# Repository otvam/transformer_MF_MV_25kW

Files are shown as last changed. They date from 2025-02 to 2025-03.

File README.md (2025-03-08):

# 25kW/50kHz MF/MV Transformer / CAD files






This repository contains the **CAD files** for a 25kW/50kHz **medium-frequency and medium-voltage transformer**.
The transformer was used in a Solid-State Transformer (SST) demonstrator using 10 kV SiC MOSFETs.
This transformer feature a full-load efficiency of 99.65% with a power density of 7.4 kW/l.

The **transformer design, construction, and measurement** are presented in **following thesis**:
* Thomas Guillod (research group of Prof. Kolar)
* Modeling and Design of Medium-Frequency Transformers for Future Medium-Voltage Power Electronics Interfaces
* Doctoral Thesis, ETH Zurich, Switzerland, 2018
* https://doi.org/10.3929/ethz-b-000353785

## Part List

The following folders contain the parts in various formats:
* [drawing](drawing) - Technical drawings (PDF format)
* [inventor](inventor) - CAD source files (INVENTOR format)
* [step](step) - CAD export files (STEP format)

Additionnaly, the following parts are used:
* Fan Connector : Phoenix 1899139
* NTC Connector : 3M 960104-6202-AR
* Axial Fan: Sunon ME50100V1-000U-A99
* Magnetic Core: Blinzinger U93/60/30 (customized U93/76/30)
* LV Litz Wire : Von Roll  Litz 2500x100 um (custom design)
* HV Litz Wire : Pack Litz 630x71 um (custom design)

For the assembly, the following compounds are used:
* MG Chemicals 8331 (grounding of the cores)
* Dow Corning TC4605 HLV (potting silicone)
* Loctite 3090 (coil former assembling)

The CAD model has the following shortcomings:
* The slots for the temperature cable sensors is too narrow.
* The holes for injecting the silicone potting are not included.
* The space for the cable terminations is very tight (difficult to assemble).
* The MV coil former is fragile and should be handled with care during the assembly.
* For testing a single fan (NMB 11925SA-12Q) has been used (instead of the six small fans).

### Gallery

<p float="middle">
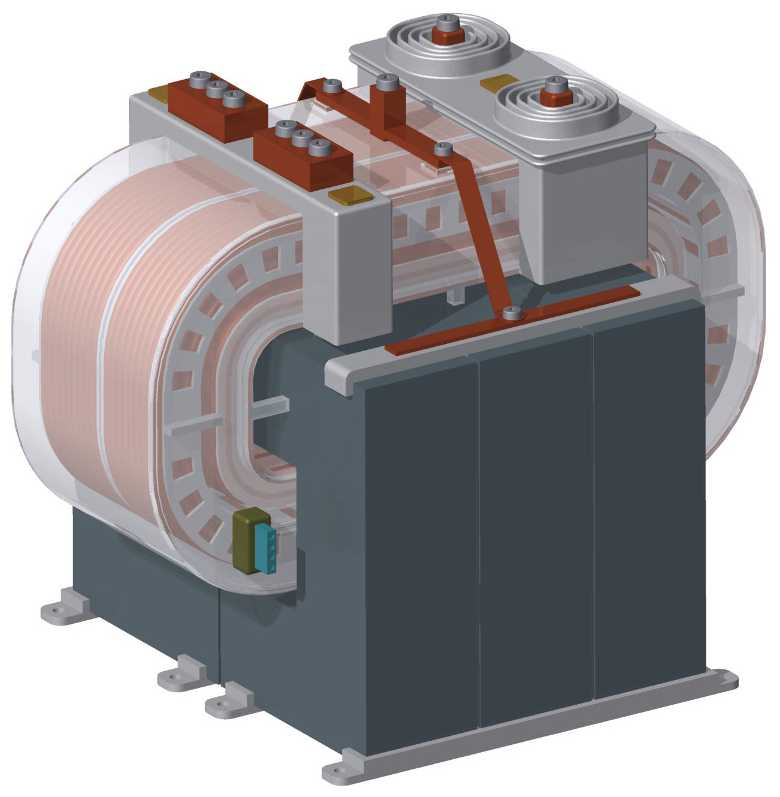
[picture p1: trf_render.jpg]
    
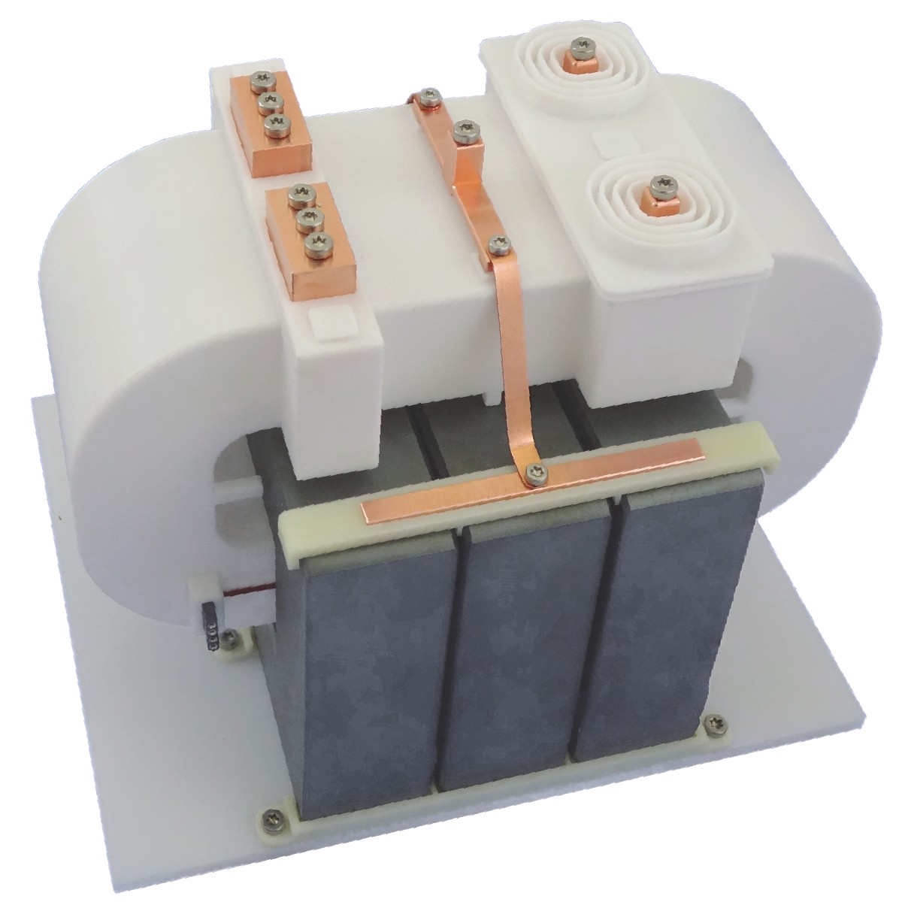
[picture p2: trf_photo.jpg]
    
</p>

## Author

* **Thomas Guillod, ETH Zurich, Power Electronic Systems Laboratory** - [GitHub Profile](https://github.com/otvam)

## License

* This project is licensed under the **Creative Commons — CC BY 4.0**, see [LICENSE.md](LICENSE.md).
* This project is copyrighted by: (c) 2016-2018, ETH Zurich, Power Electronic Systems Laboratory, T. Guillod.

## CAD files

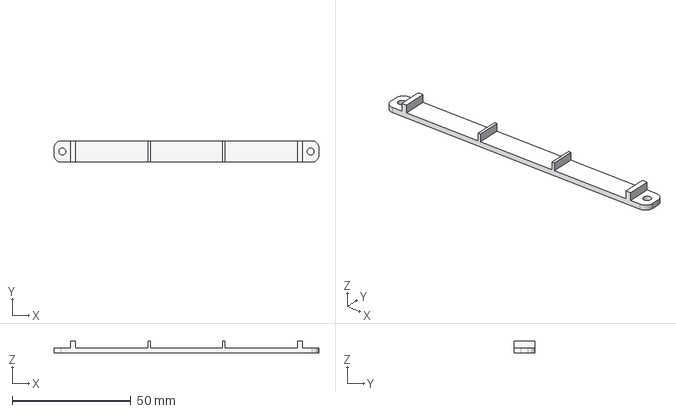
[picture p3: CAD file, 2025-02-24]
step/base_gap.ipt.stp
111.5 x 9.00 x 5.00 mm

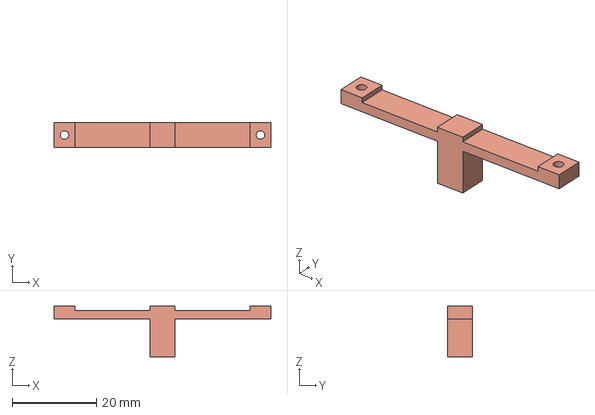
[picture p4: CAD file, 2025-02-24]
step/termination_gnd.ipt.stp
51.5 x 6.00 x 12.0 mm

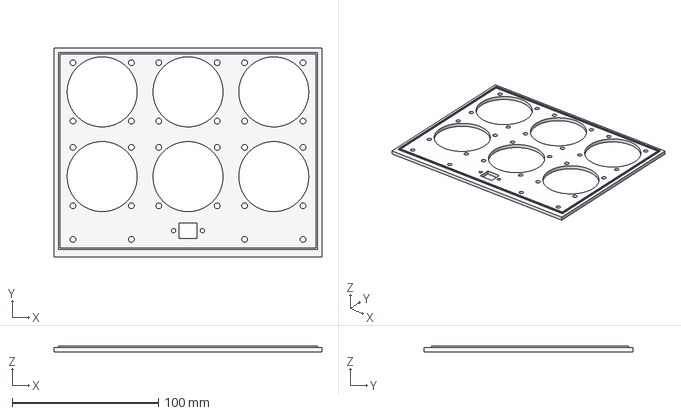
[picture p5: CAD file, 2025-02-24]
step/plate_ext.ipt.stp
183.5 x 143.0 x 4.00 mm

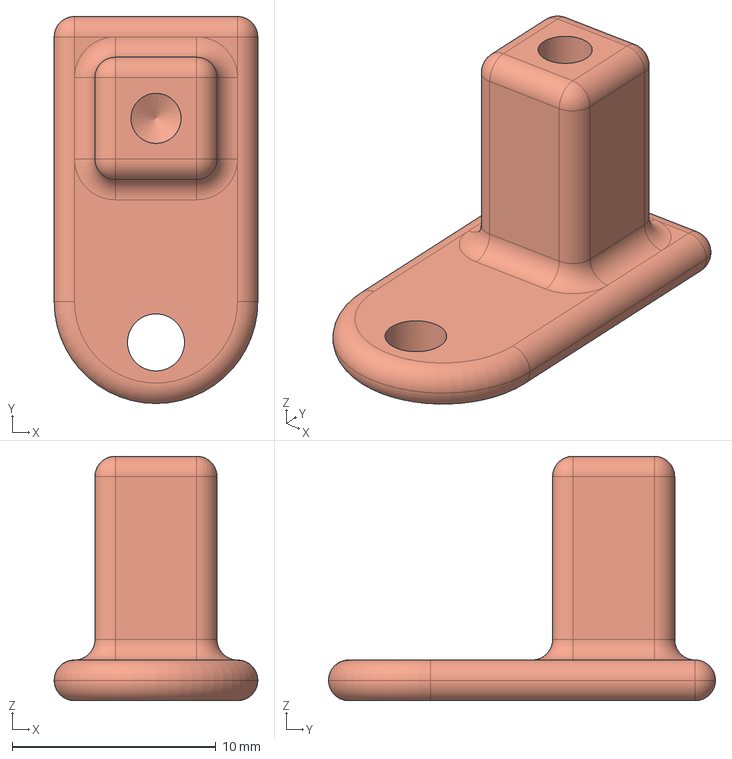
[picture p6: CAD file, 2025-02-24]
step/termination_hv_conductor.ipt.stp
10.0 x 19.0 x 12.0 mm

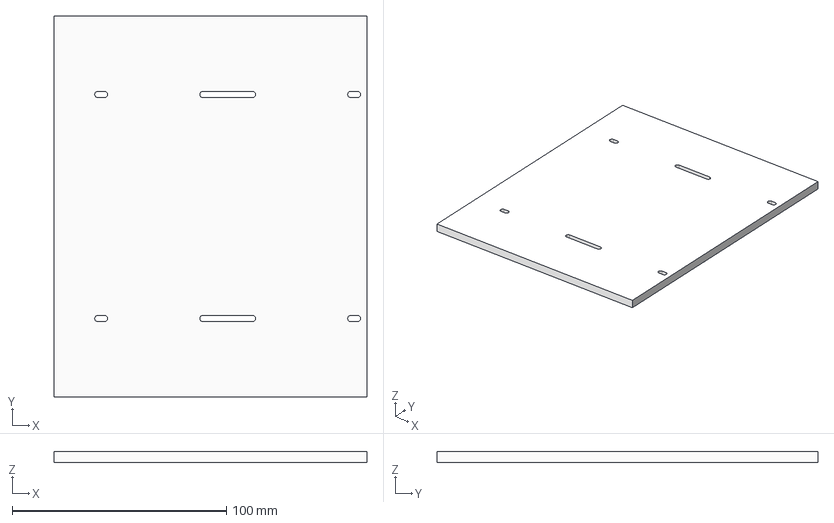
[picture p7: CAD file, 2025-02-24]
step/plate_base.ipt.stp
146.0 x 177.5 x 5.00 mm

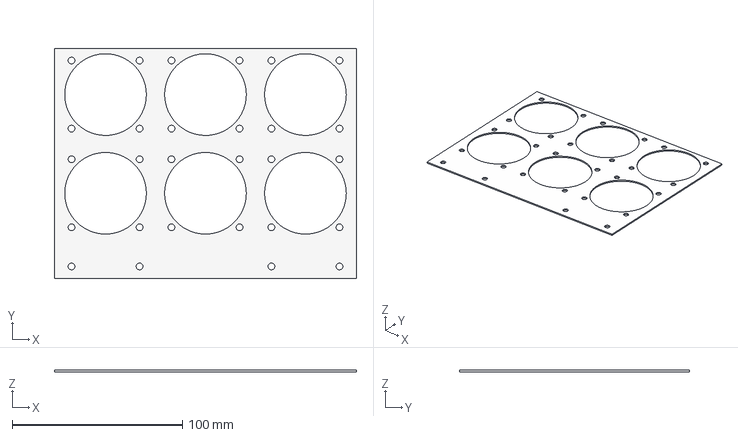
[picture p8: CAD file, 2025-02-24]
step/plate_int.ipt.stp
177.5 x 135.0 x 1.00 mm

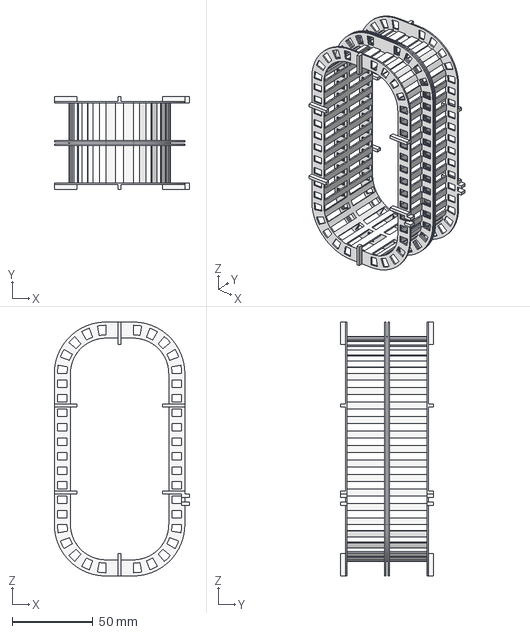
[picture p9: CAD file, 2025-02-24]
step/coil_former_hv.ipt.stp
84.0 x 57.5 x 157.5 mm

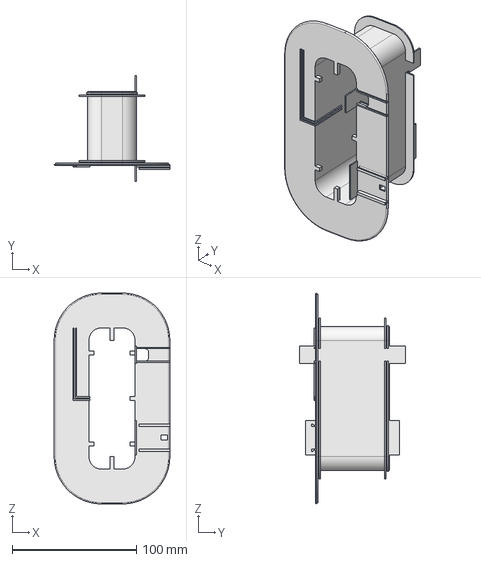
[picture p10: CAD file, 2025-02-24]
step/coil_former_lv.ipt.stp
93.0 x 85.5 x 169.5 mm

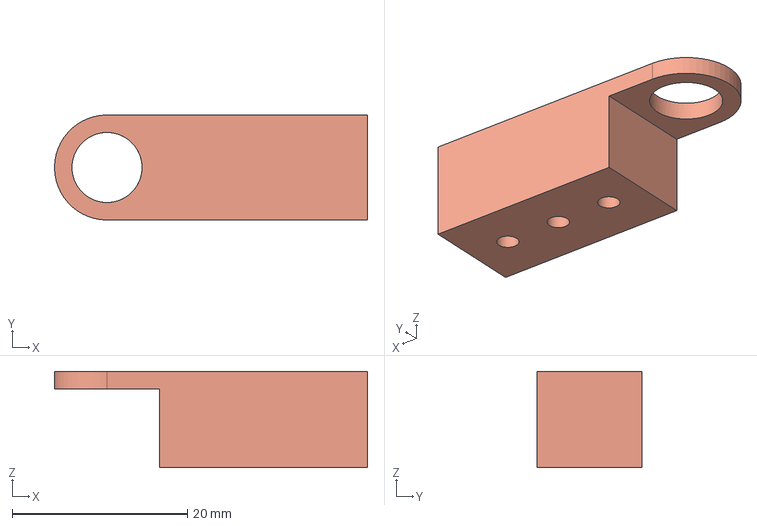
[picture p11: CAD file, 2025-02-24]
step/termination_lv_conductor.ipt.stp
35.8 x 12.0 x 11.0 mm

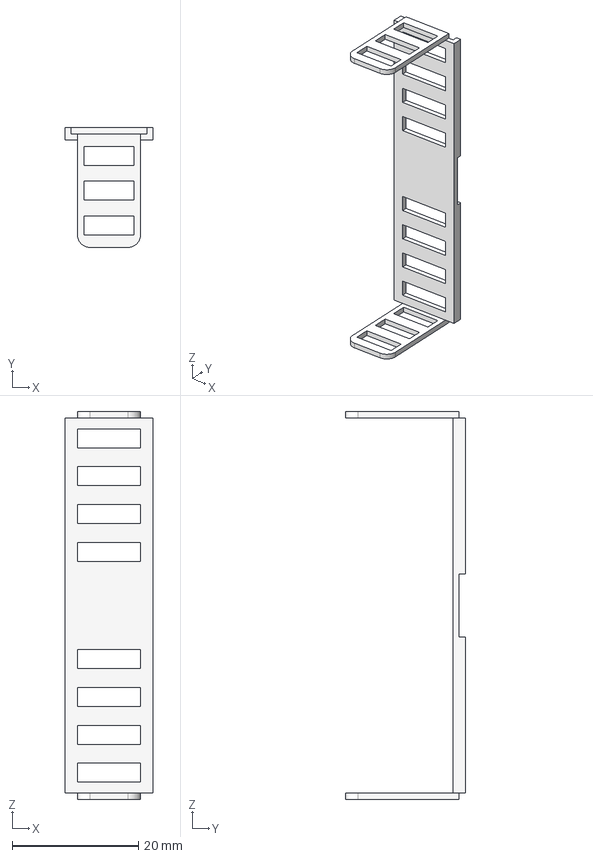
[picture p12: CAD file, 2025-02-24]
step/termination_lv_insulation.ipt.stp
14.0 x 19.0 x 61.5 mm

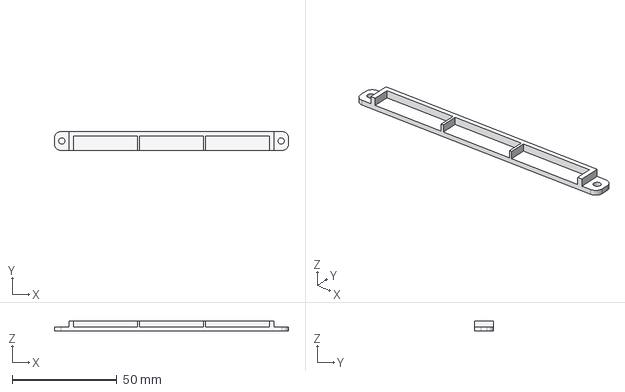
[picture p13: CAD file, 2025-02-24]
step/base_corner.ipt.stp
111.5 x 9.00 x 5.00 mm

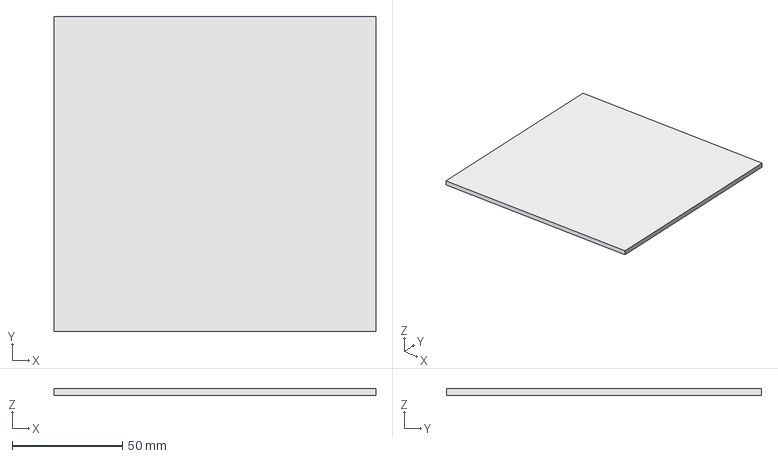
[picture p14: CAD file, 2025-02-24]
step/plate_side.ipt.stp
146.0 x 143.0 x 3.00 mm

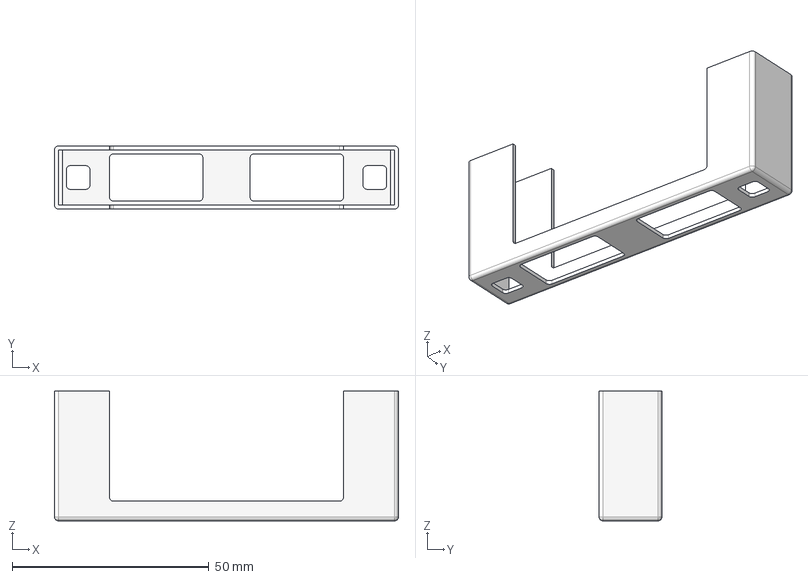
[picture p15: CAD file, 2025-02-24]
step/termination_lv_cover.ipt.stp
87.5 x 16.0 x 33.0 mm

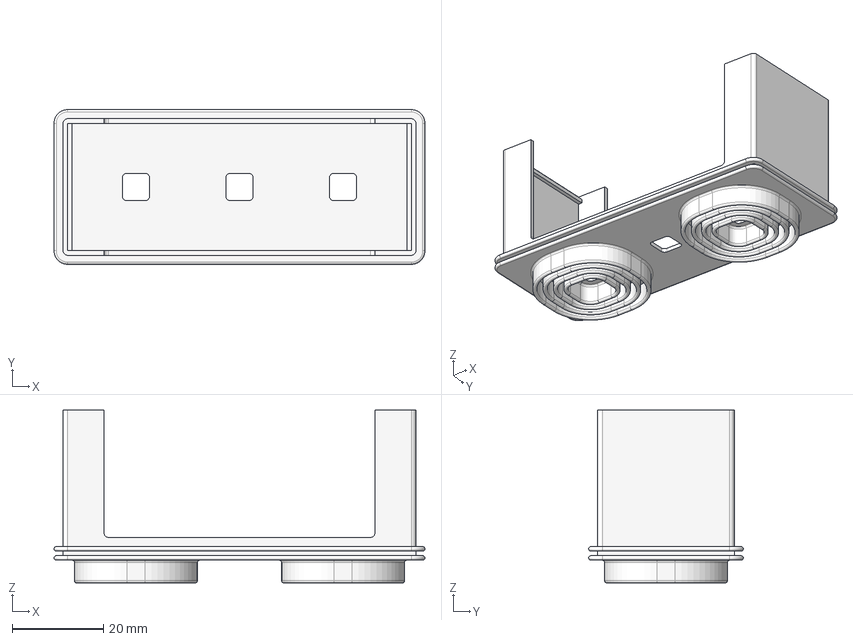
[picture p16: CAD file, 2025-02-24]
step/termination_hv_cover.ipt.stp
81.5 x 34.0 x 38.0 mm

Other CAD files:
step/top_spacer.ipt.stp
step/core_earth.ipt.stp
step/plate_out.ipt.stp
inventor/base_corner.ipt
inventor/base_gap.ipt
inventor/coil_former_hv.ipt
inventor/coil_former_lv.ipt
inventor/coil_former_mold.ipt
inventor/core_earth.ipt
inventor/plate_base.ipt
inventor/plate_ext.ipt
inventor/plate_int.ipt
inventor/plate_out.ipt
inventor/plate_side.ipt
inventor/plate_top.ipt
inventor/temperature_cover.ipt
inventor/termination_closing.ipt
inventor/termination_gnd.ipt
inventor/termination_hv_conductor.ipt
inventor/termination_hv_cover.ipt
inventor/termination_lv_conductor.ipt
inventor/termination_lv_cover.ipt
inventor/termination_lv_insulation.ipt
inventor/top_conductor.ipt
inventor/top_spacer.ipt
step/coil_former_mold.ipt.stp
step/temperature_cover.ipt.stp
step/termination_closing.ipt.stp
step/top_conductor.ipt.stp

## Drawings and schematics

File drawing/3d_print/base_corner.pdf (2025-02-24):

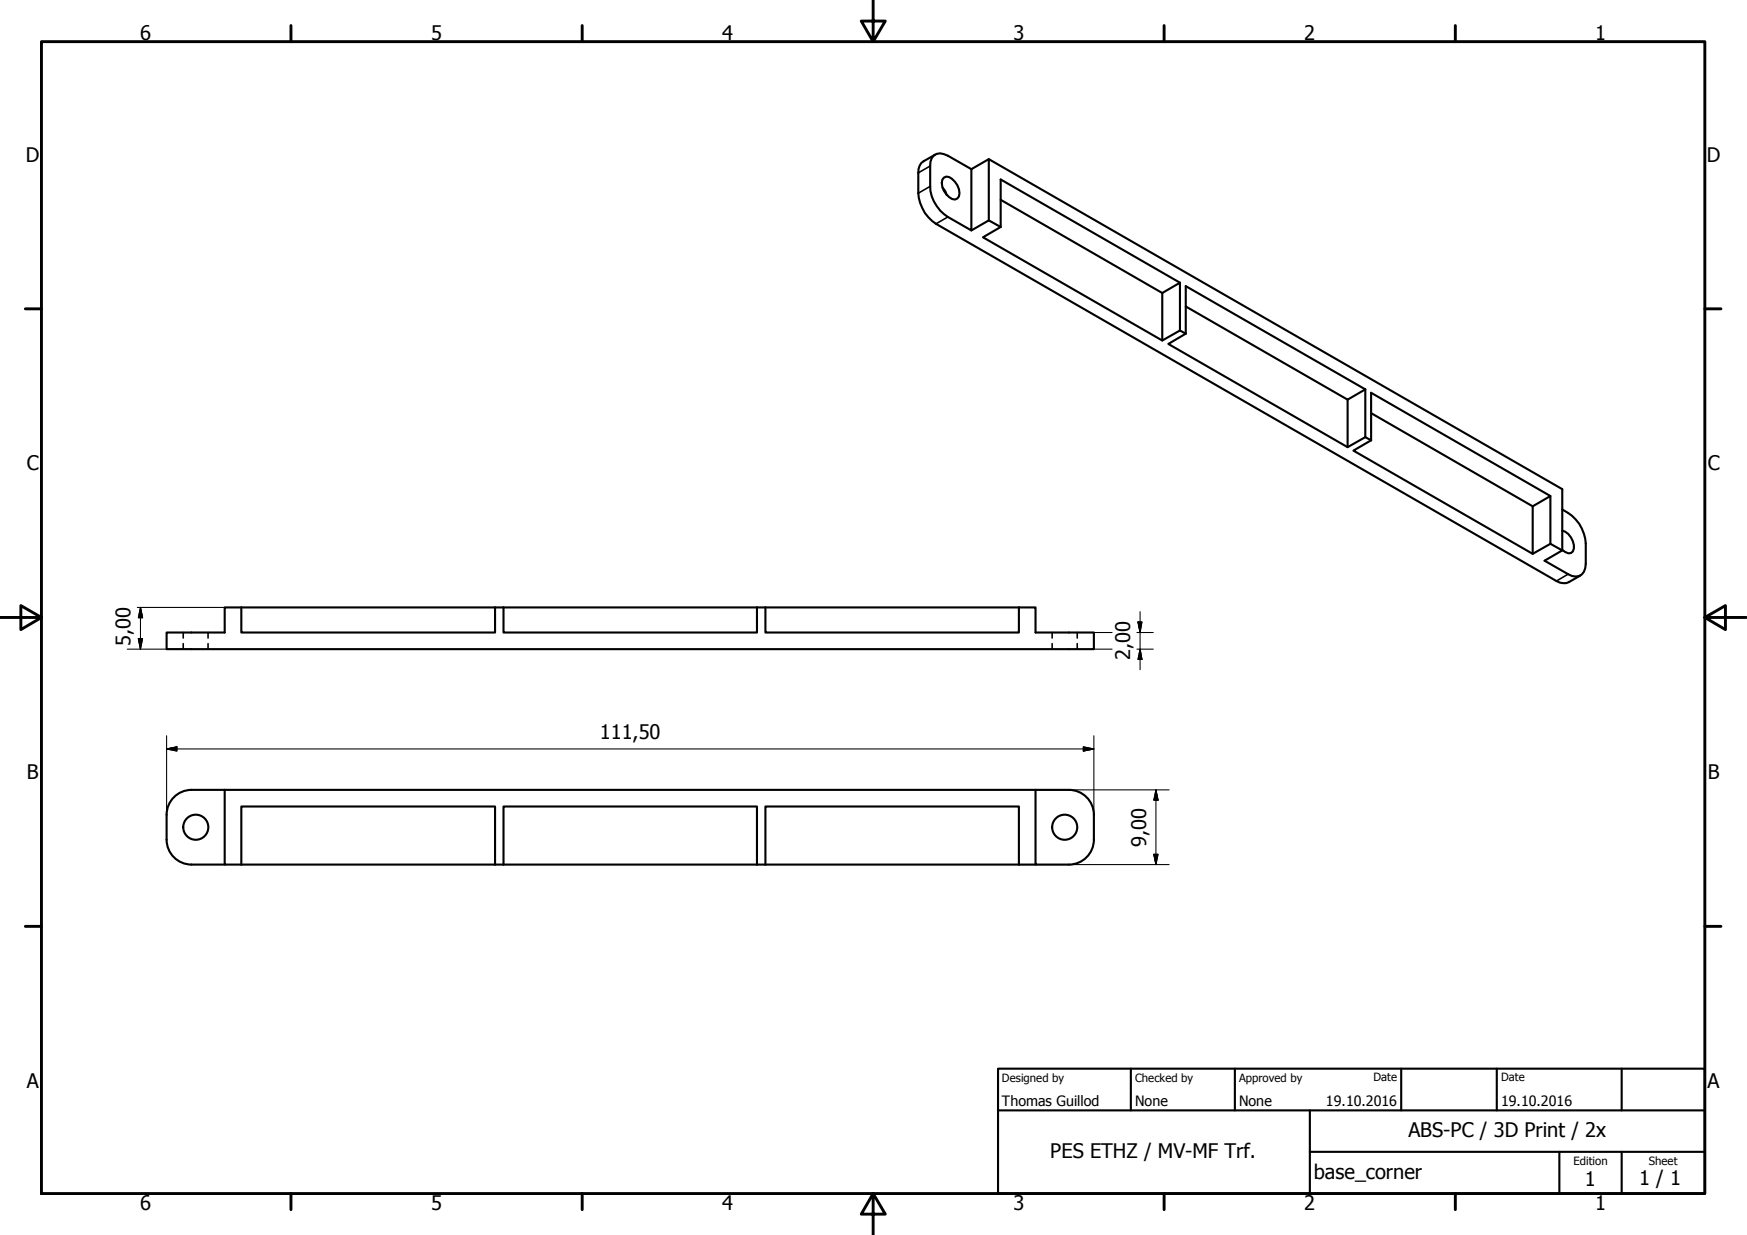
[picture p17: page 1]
base_corner; Thomas Guillod; None; Designed by; Checked by; Approved by; Date; Edition; Sheet

ABS-PC / 3D Print / 2x

PES ETHZ / MV-MF Trf.

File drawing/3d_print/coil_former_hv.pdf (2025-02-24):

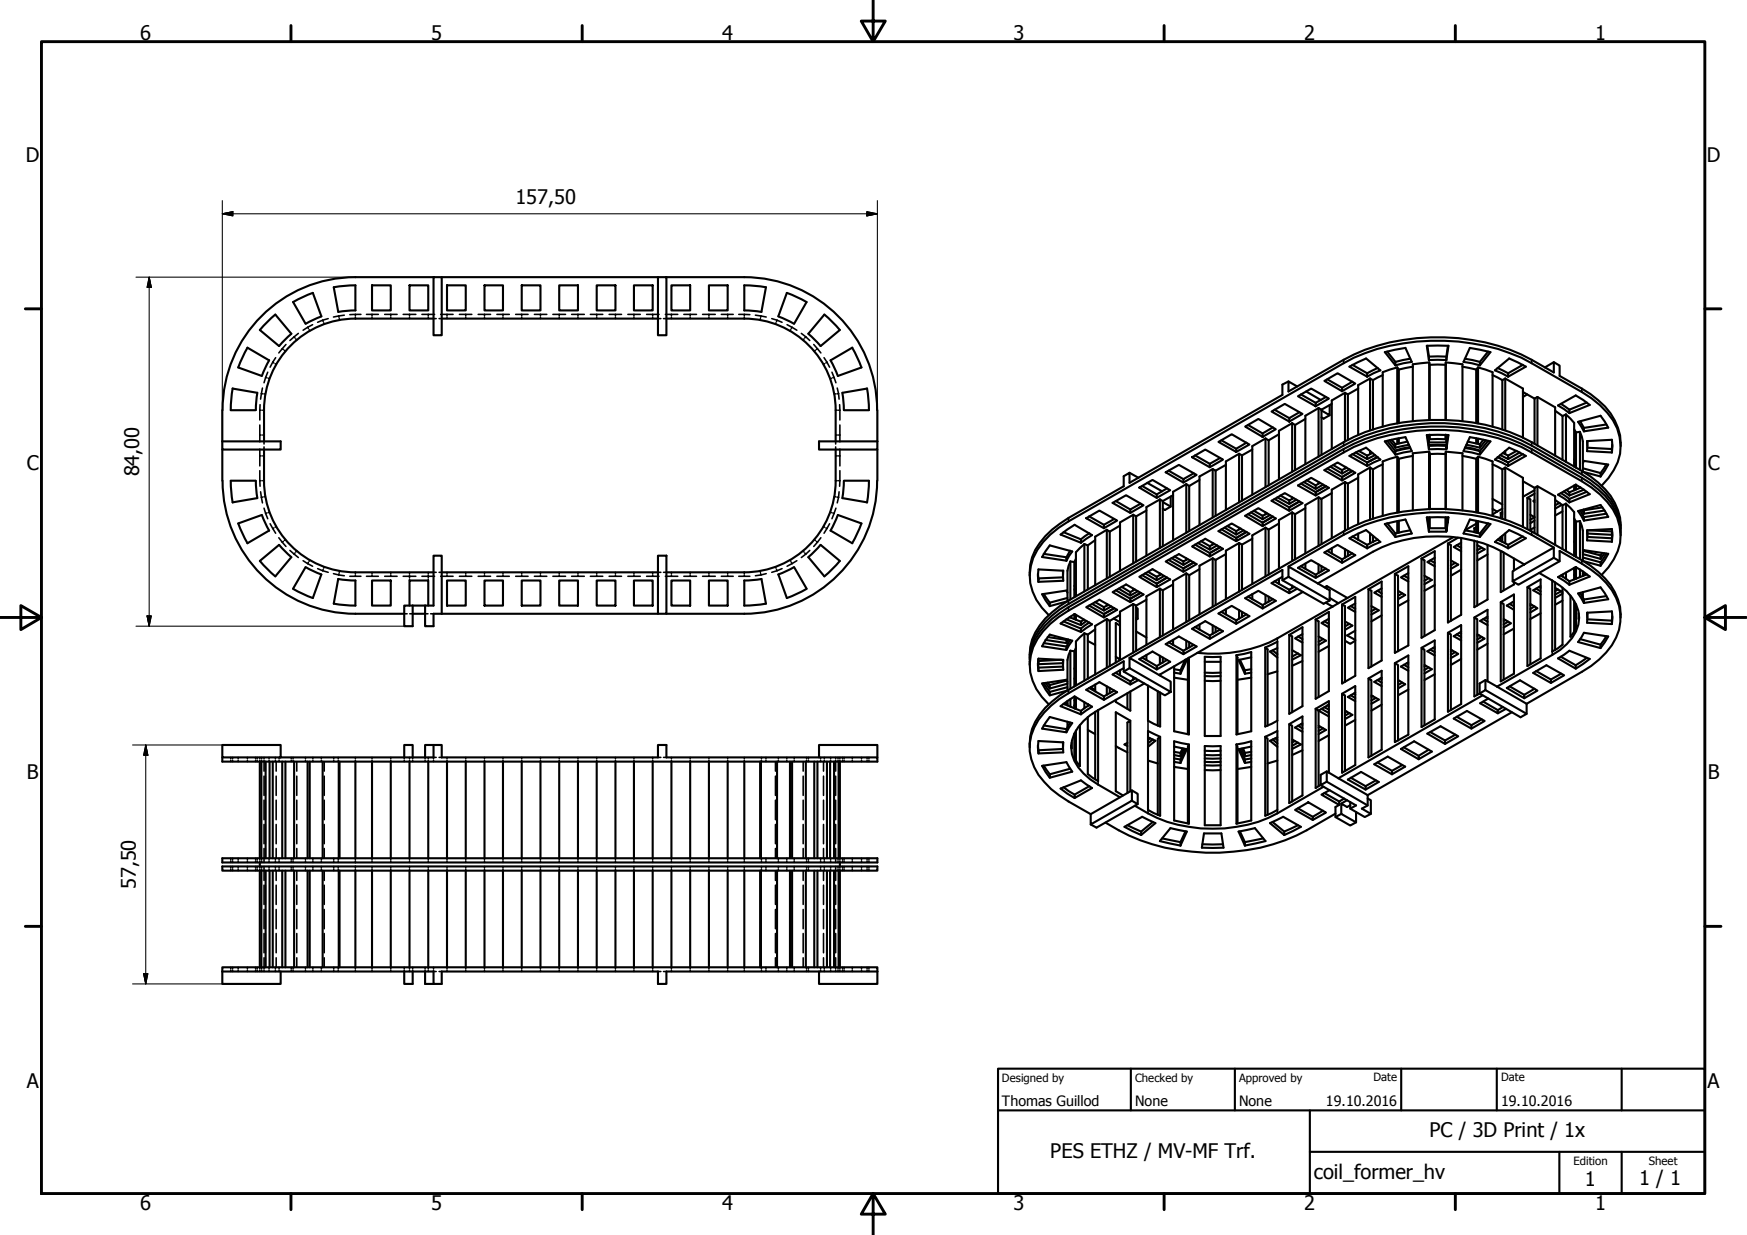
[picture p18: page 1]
PC / 3D Print / 1x; coil_former_hv; Thomas Guillod; None; Designed by; Checked by; Approved by; Date; Edition; Sheet

PES ETHZ / MV-MF Trf.

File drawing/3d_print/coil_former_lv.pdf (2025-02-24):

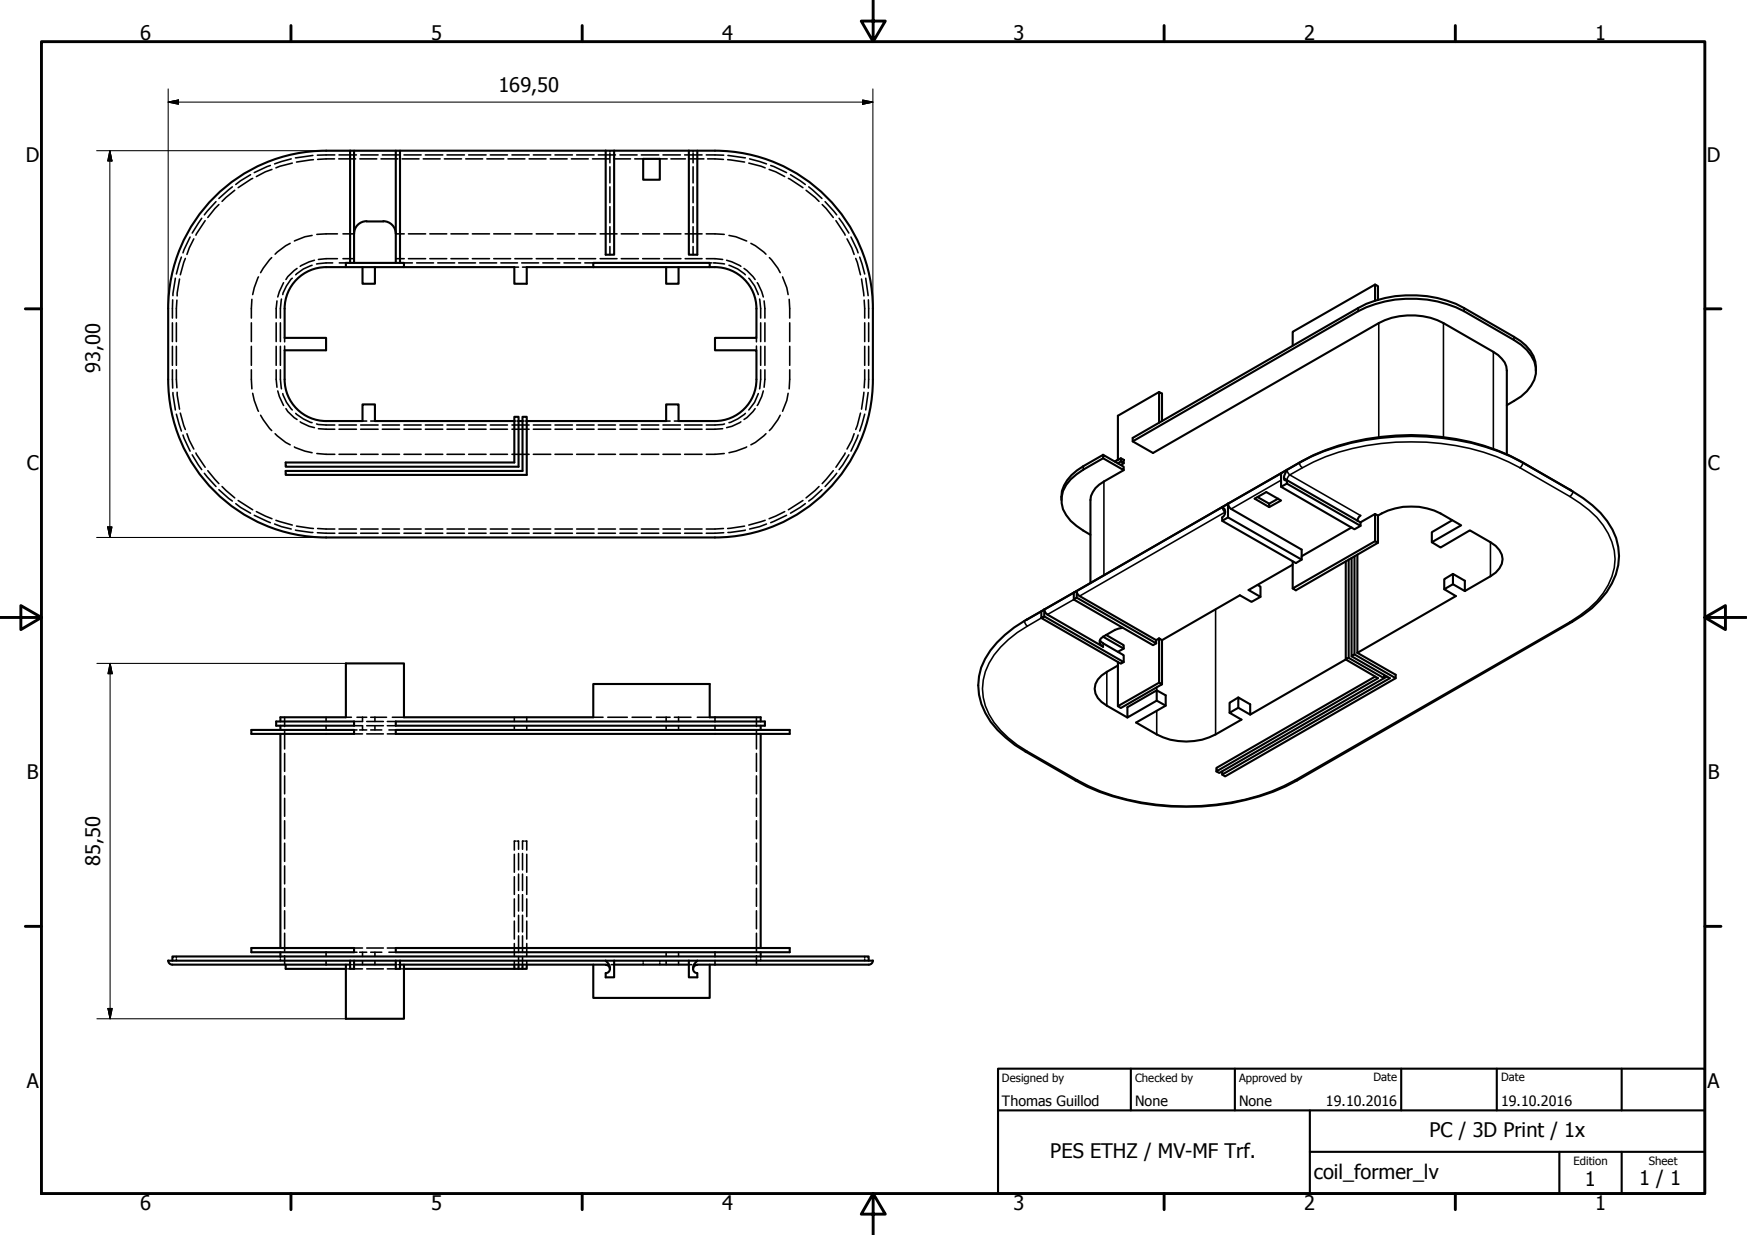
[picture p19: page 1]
PC / 3D Print / 1x; coil_former_lv; Thomas Guillod; None; Designed by; Checked by; Approved by; Date; Edition; Sheet

PES ETHZ / MV-MF Trf.

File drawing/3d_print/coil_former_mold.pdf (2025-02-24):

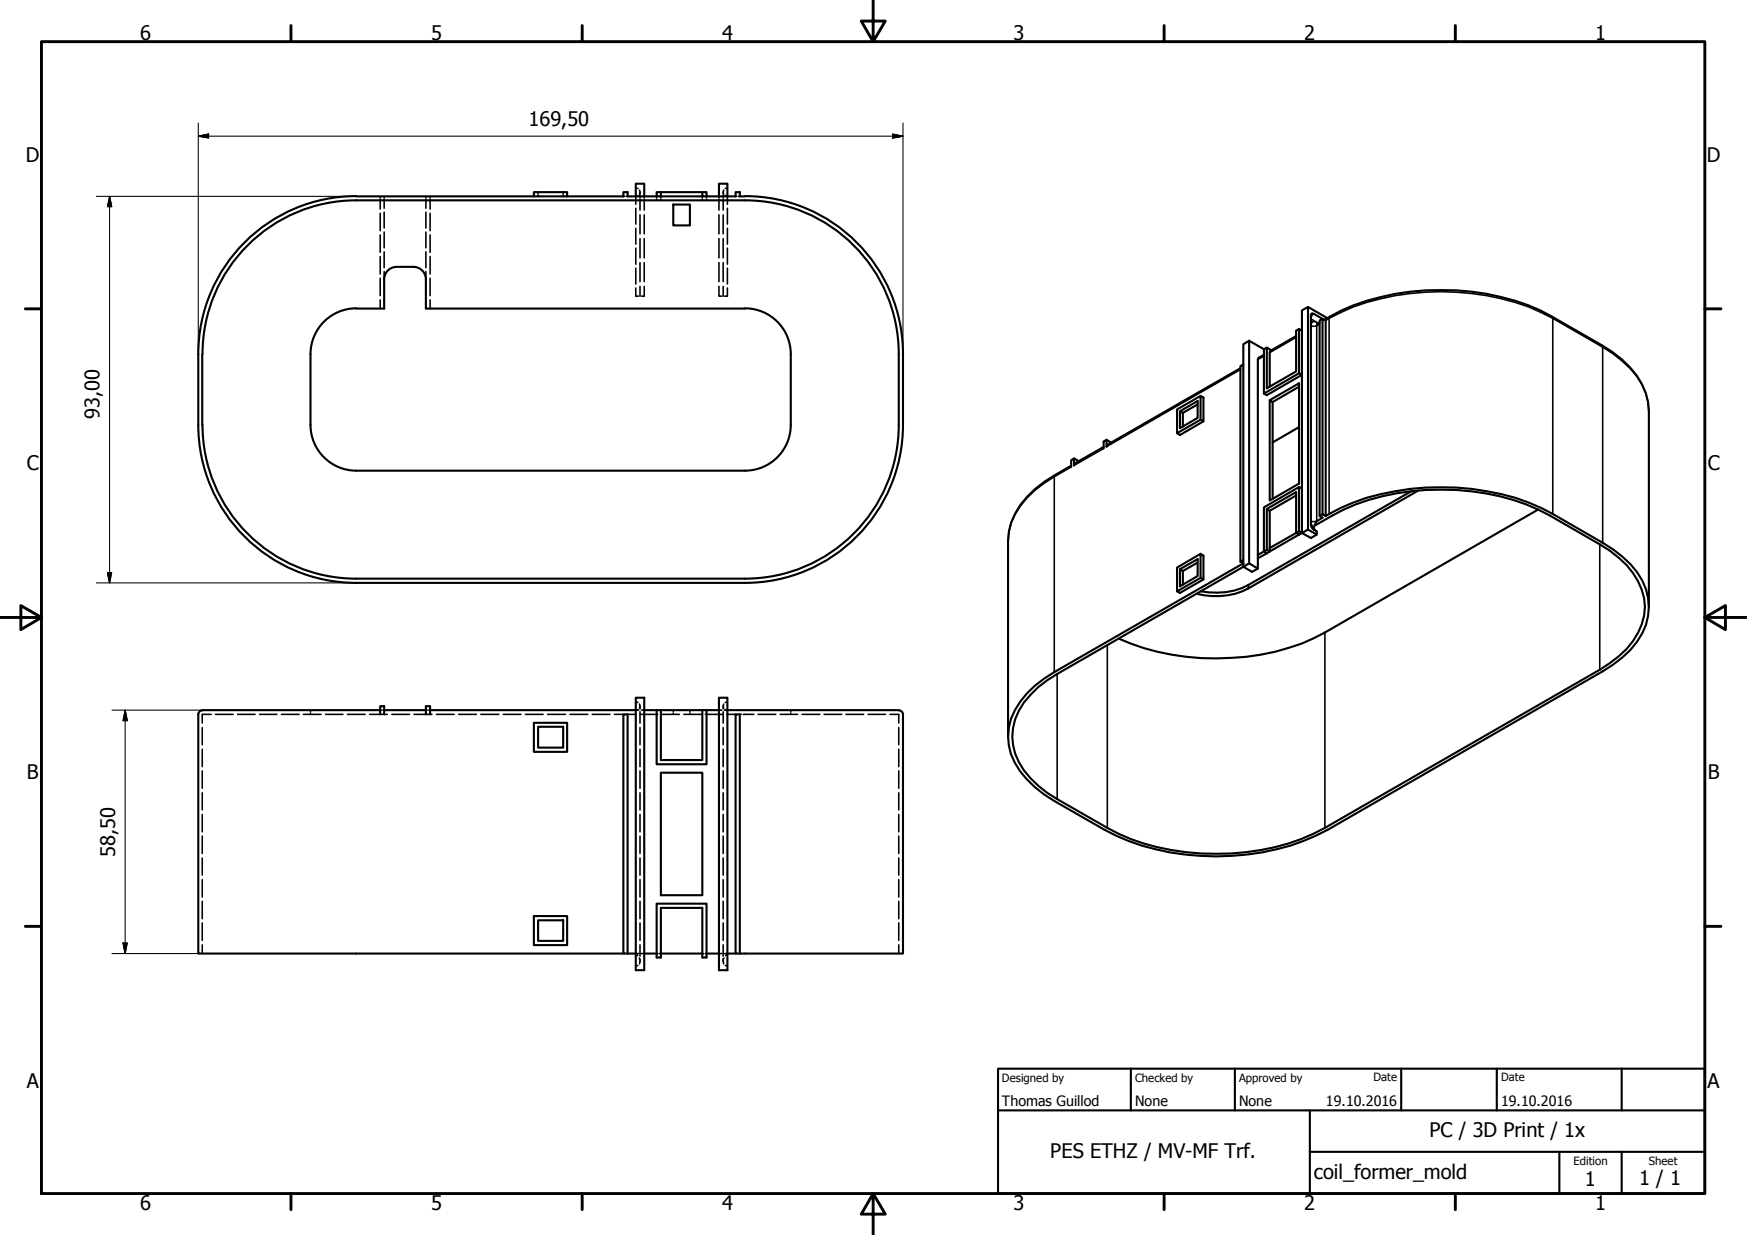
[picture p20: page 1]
PC / 3D Print / 1x; coil_former_mold; Thomas Guillod; None; Designed by; Checked by; Approved by; Date; Edition; Sheet

PES ETHZ / MV-MF Trf.

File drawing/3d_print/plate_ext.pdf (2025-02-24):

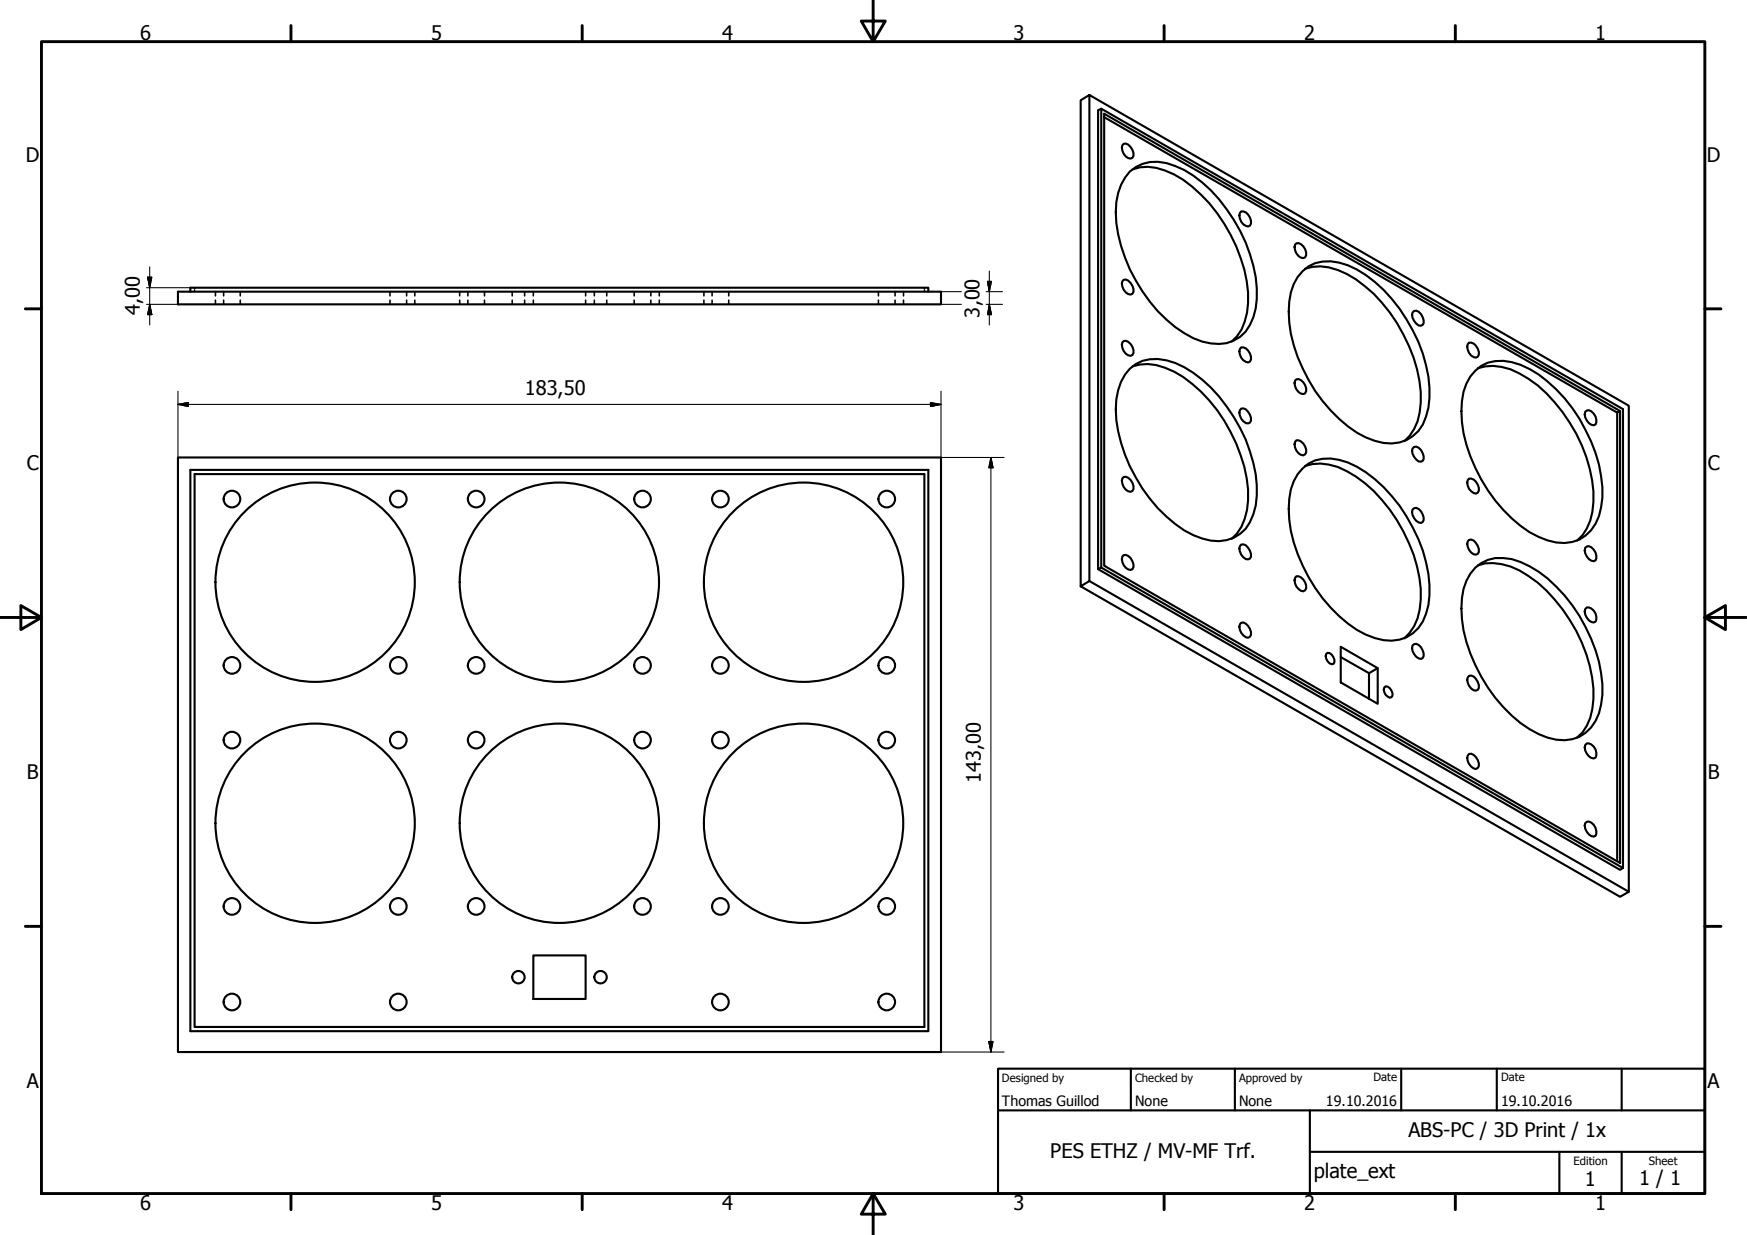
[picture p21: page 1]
plate_ext; Thomas Guillod; None; Designed by; Checked by; Approved by; Date; Edition; Sheet

ABS-PC / 3D Print / 1x

PES ETHZ / MV-MF Trf.

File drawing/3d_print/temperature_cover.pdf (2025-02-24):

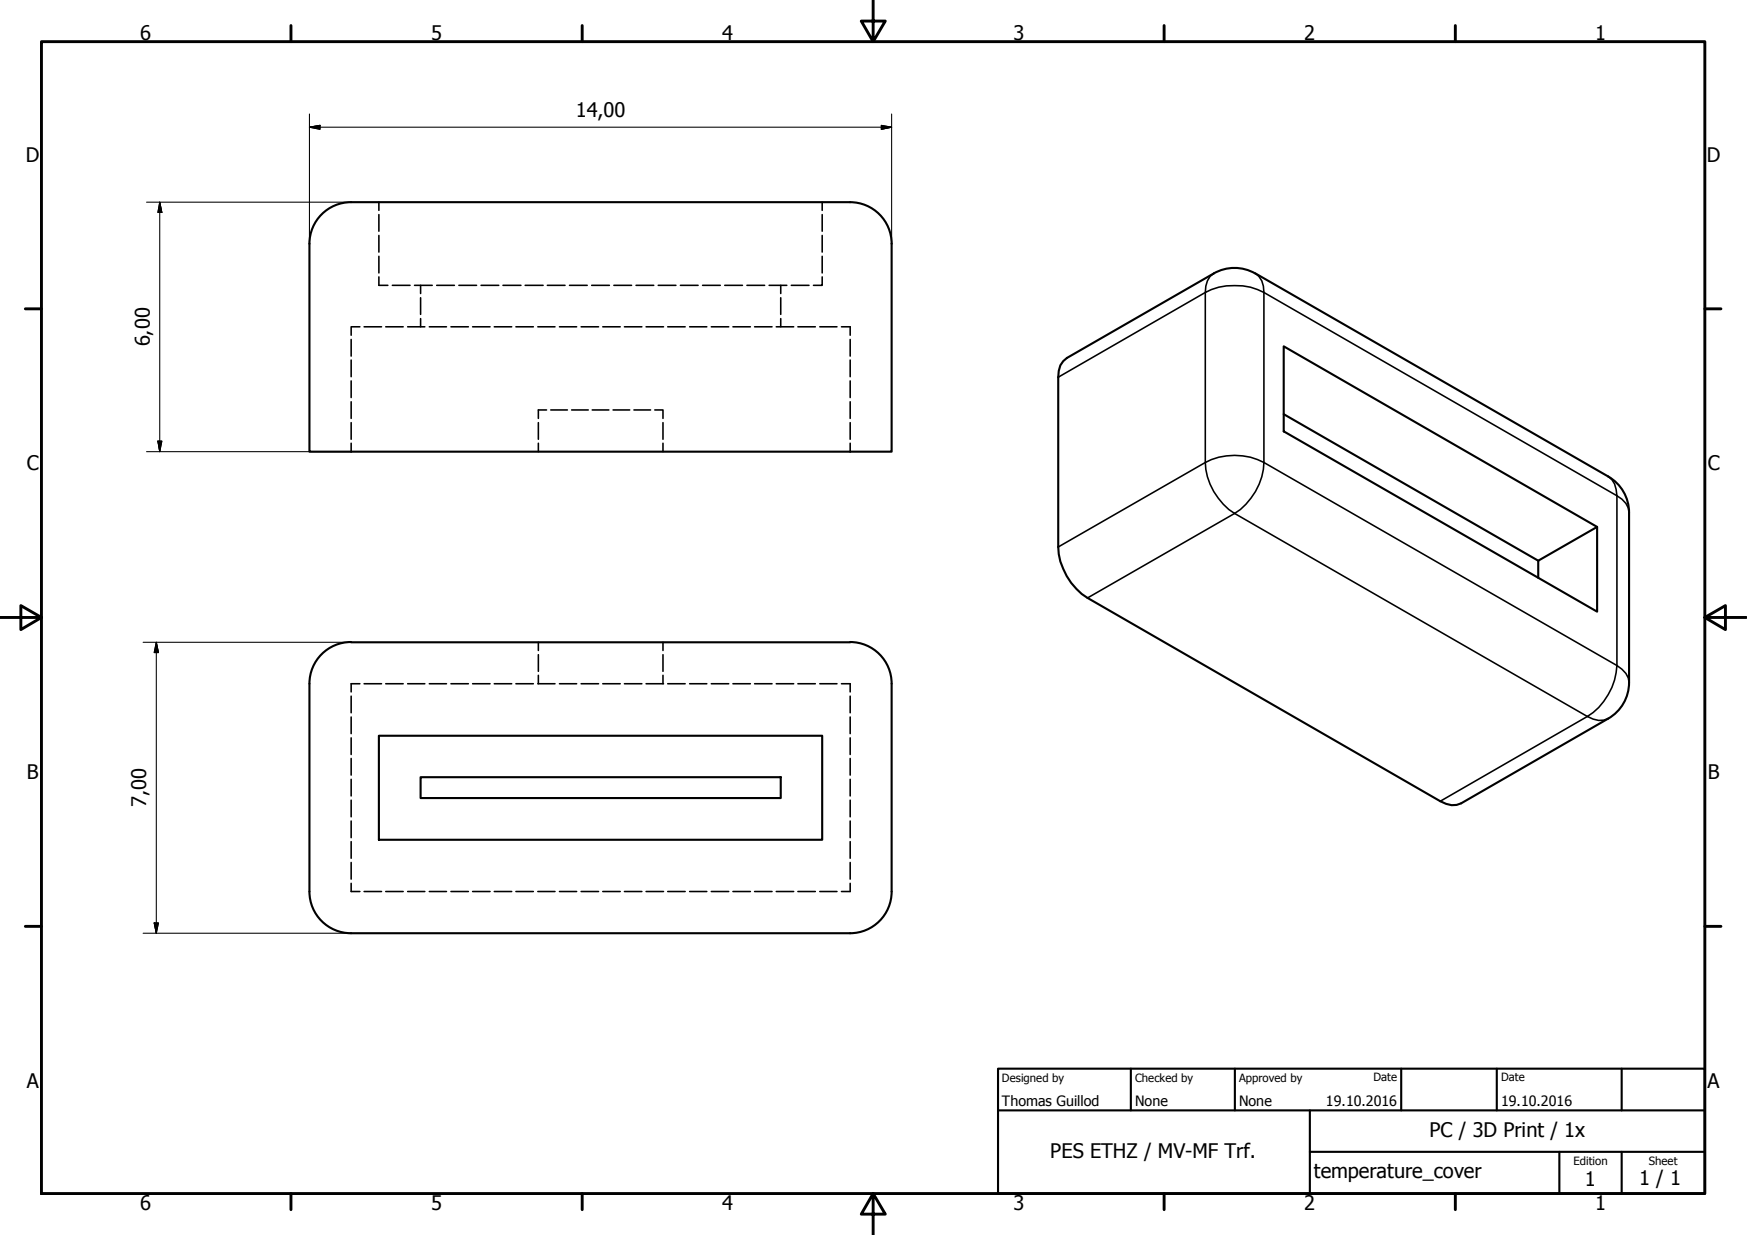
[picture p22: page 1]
PC / 3D Print / 1x; temperature_cover; Thomas Guillod; None; Designed by; Checked by; Approved by; Date; Edition; Sheet

PES ETHZ / MV-MF Trf.

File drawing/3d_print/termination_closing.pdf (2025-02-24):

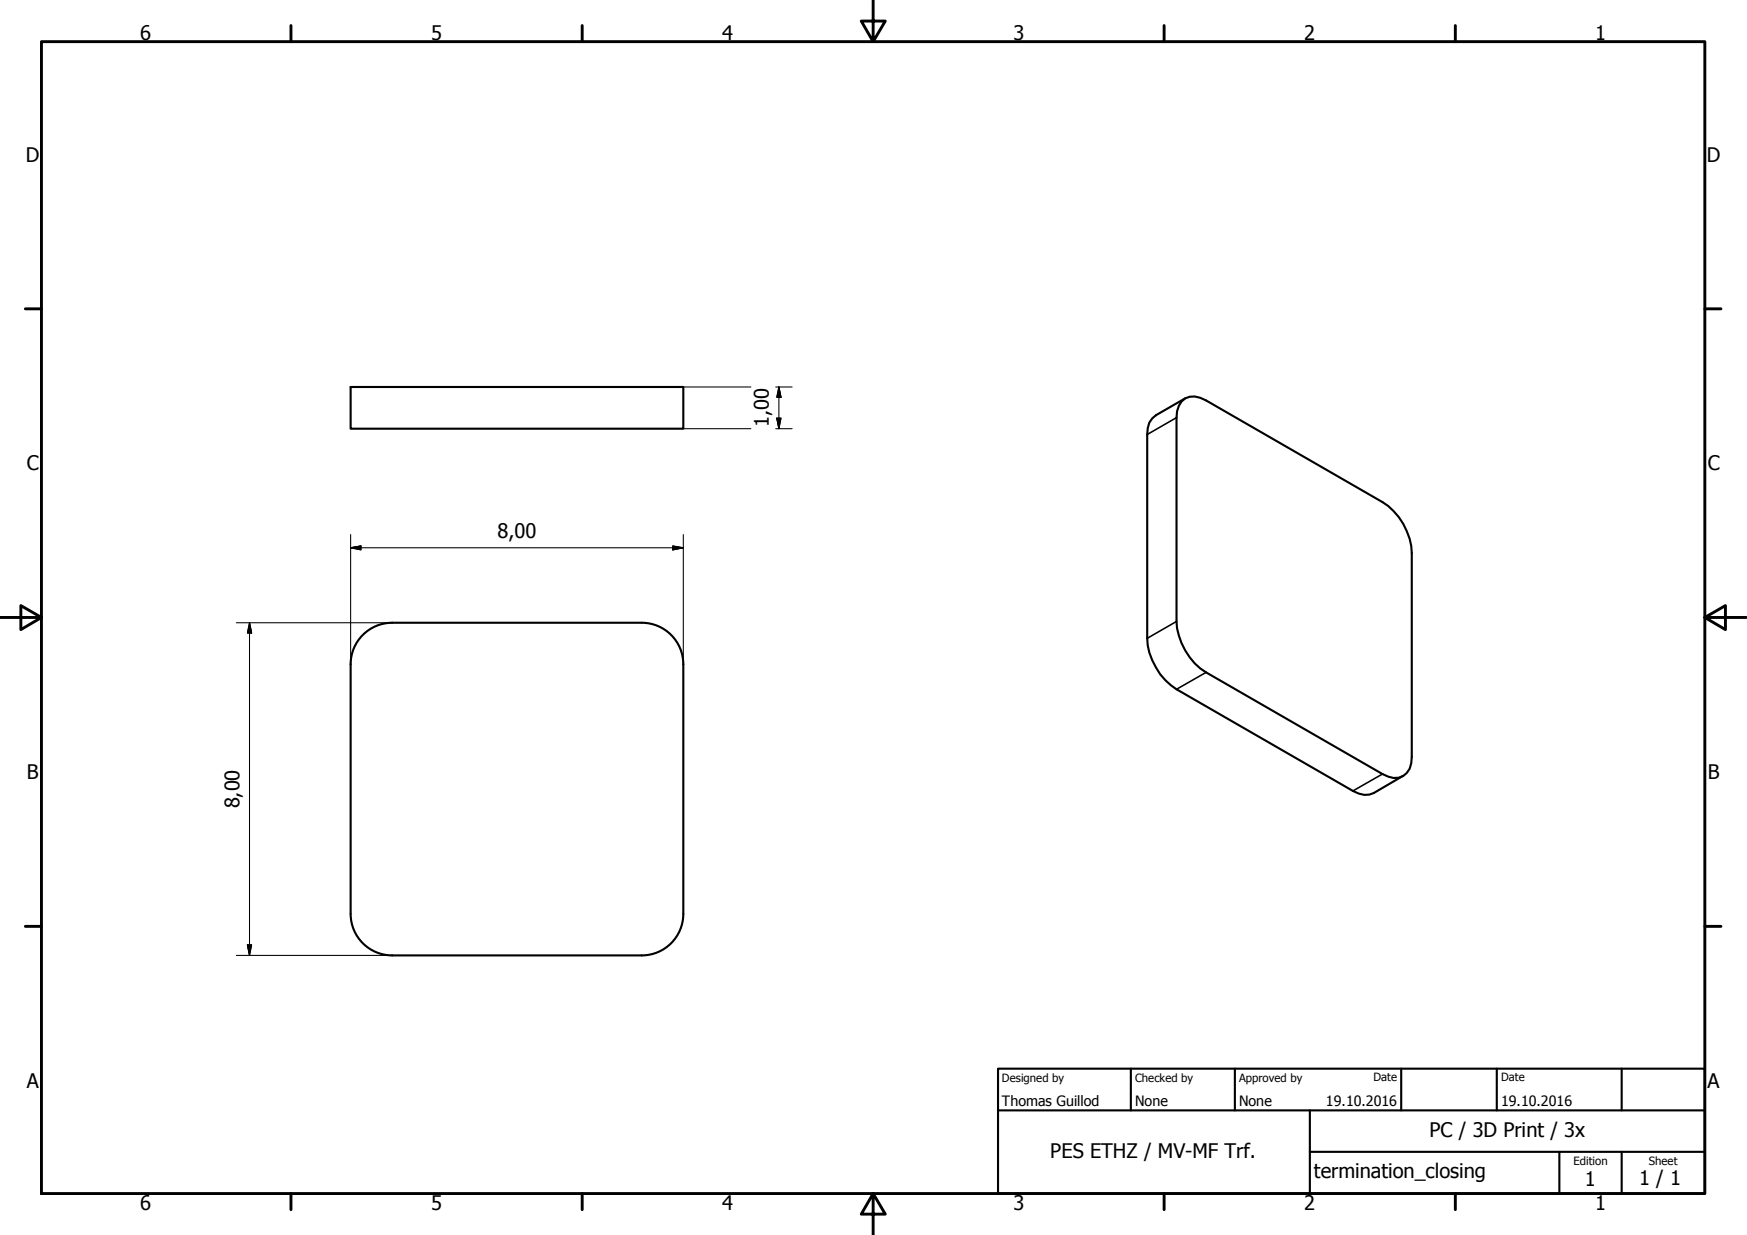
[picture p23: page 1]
PC / 3D Print / 3x; termination_closing; Thomas Guillod; None; Designed by; Checked by; Approved by; Date; Edition; Sheet

PES ETHZ / MV-MF Trf.

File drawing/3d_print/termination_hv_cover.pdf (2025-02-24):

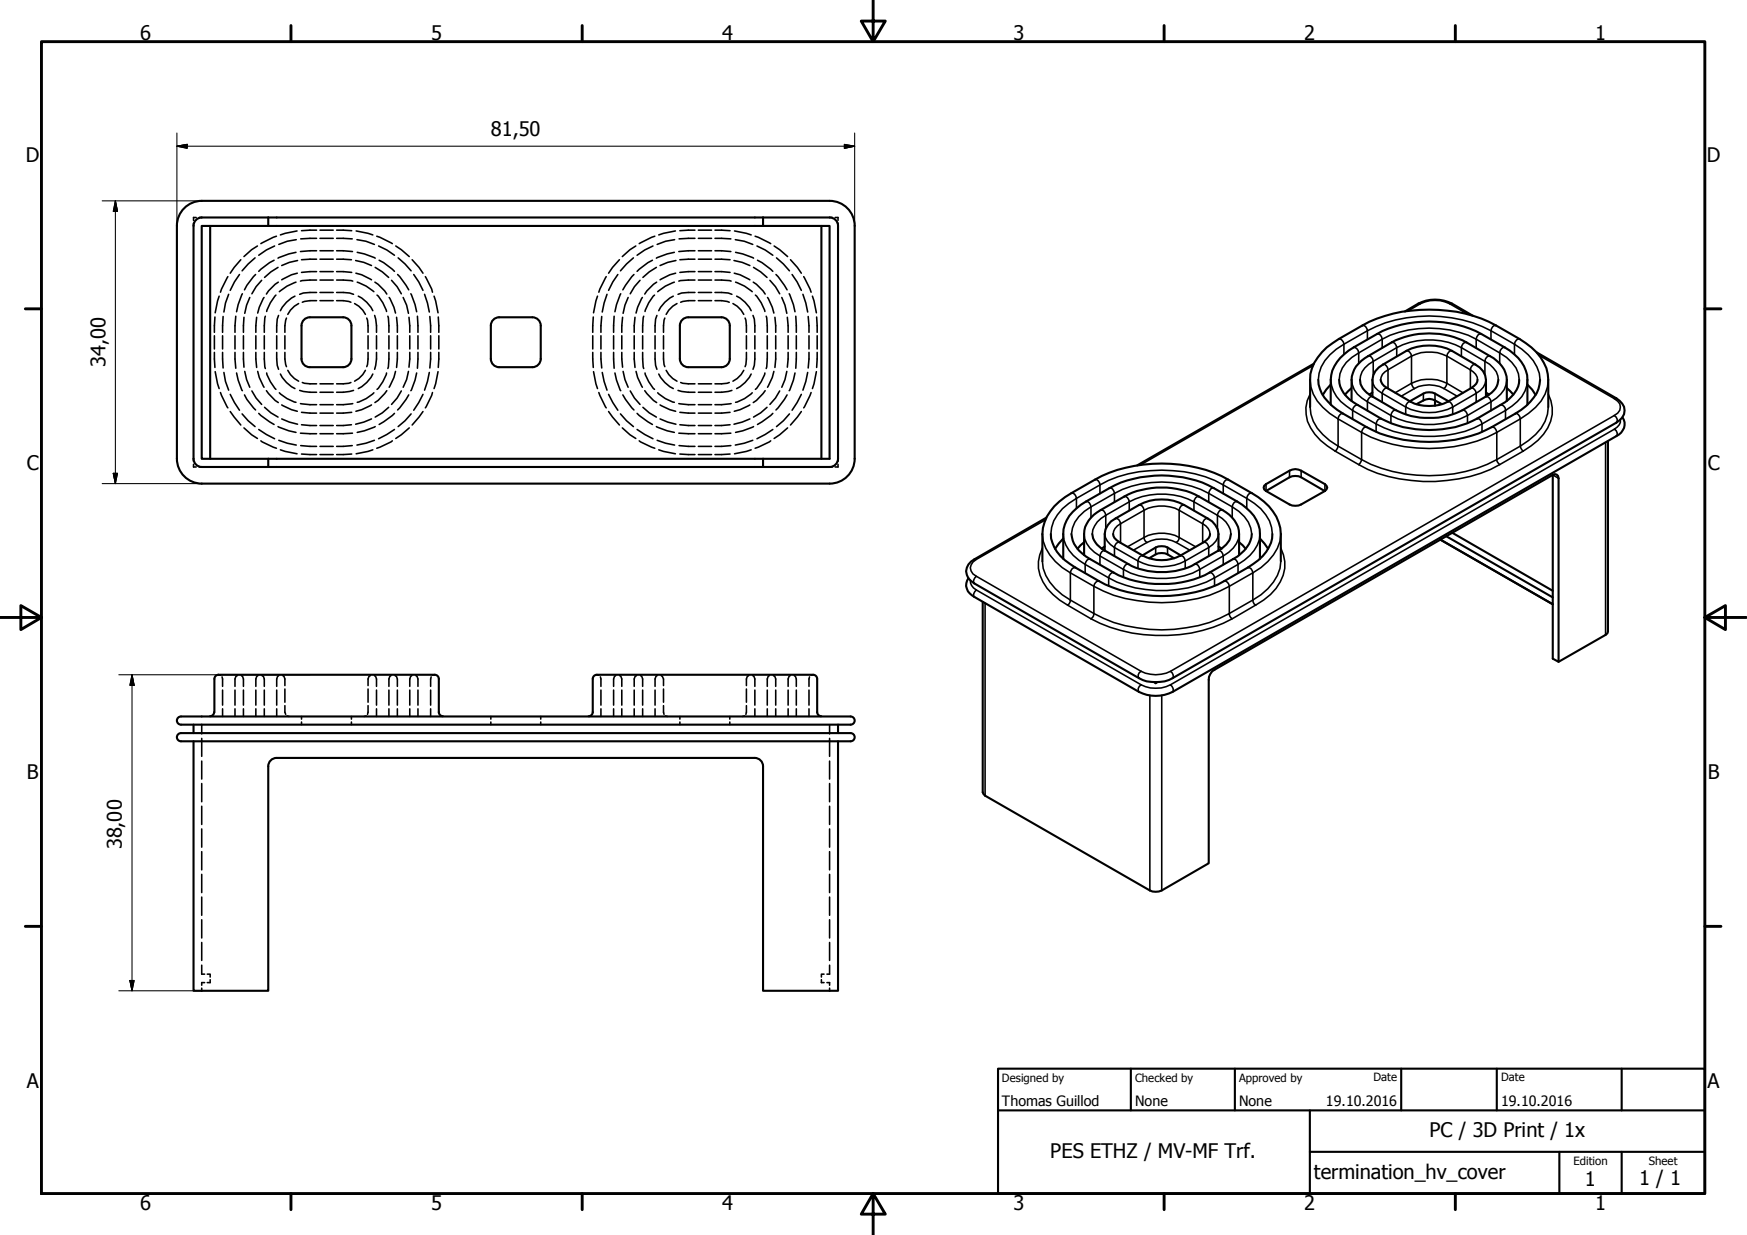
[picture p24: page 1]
PC / 3D Print / 1x; termination_hv_cover; Thomas Guillod; None; Designed by; Checked by; Approved by; Date; Edition; Sheet

PES ETHZ / MV-MF Trf.

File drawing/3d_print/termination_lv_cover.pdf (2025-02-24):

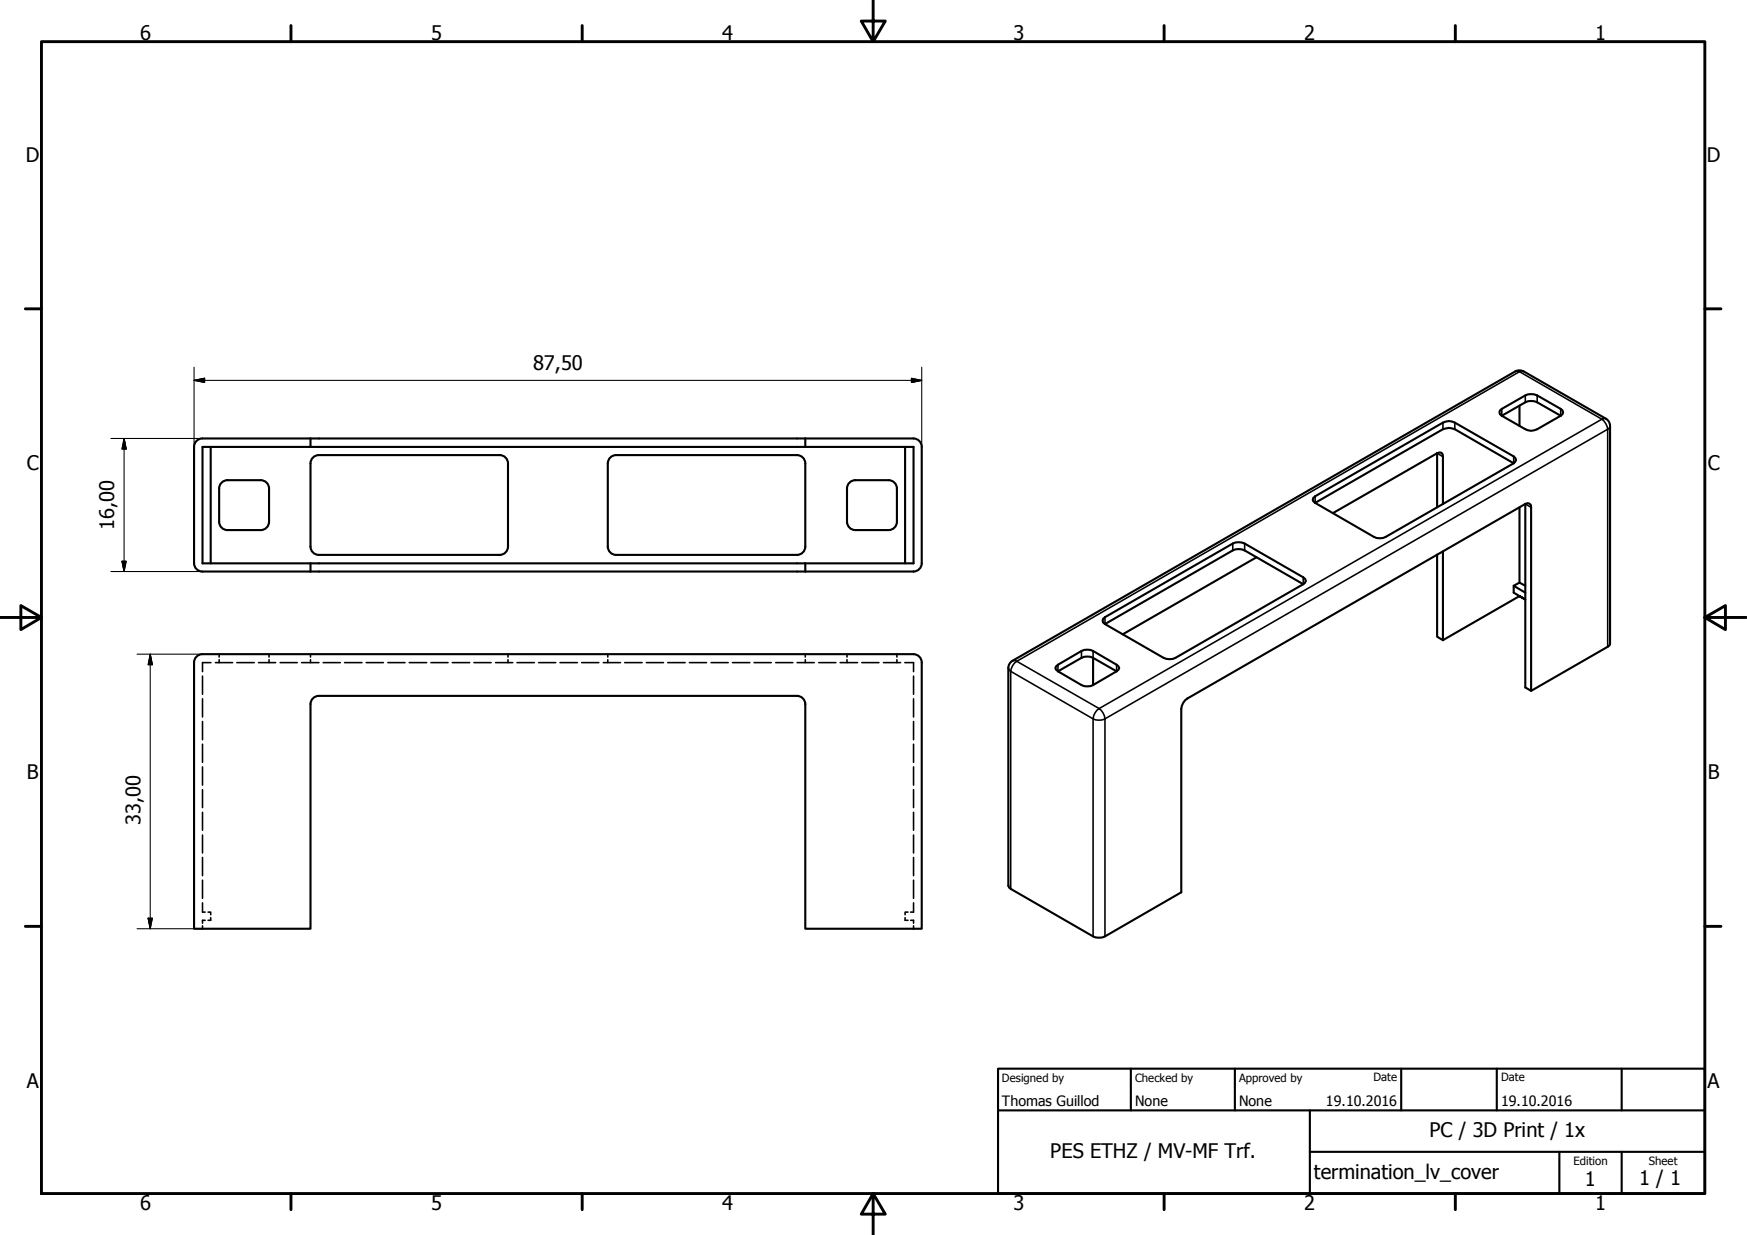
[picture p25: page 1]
PC / 3D Print / 1x; termination_lv_cover; Thomas Guillod; None; Designed by; Checked by; Approved by; Date; Edition; Sheet

PES ETHZ / MV-MF Trf.

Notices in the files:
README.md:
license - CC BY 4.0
